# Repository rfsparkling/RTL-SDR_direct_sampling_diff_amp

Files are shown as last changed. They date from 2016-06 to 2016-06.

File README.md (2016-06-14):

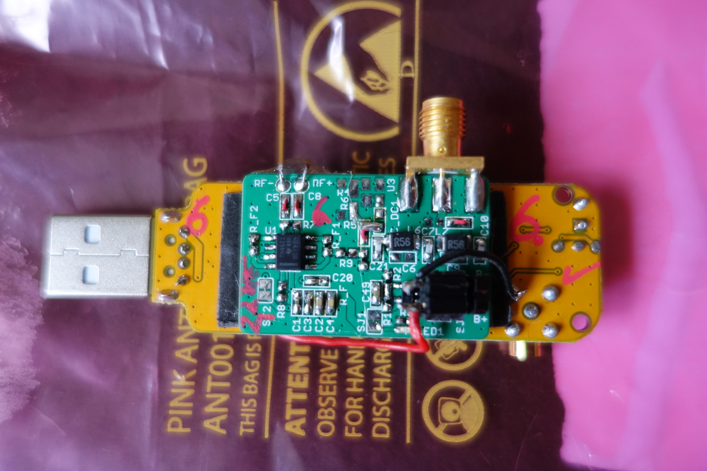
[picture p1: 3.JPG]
layout preview


This is a breakout board for stock RTL-SDR dongle, allowing the until known best direct sampling method for HF reception using a differential amplifer as BALUN. Right now filtering DC...14 MHz band but possible to work on 14...28 MHz band too after adding a Band Pass Filter BPF.

My design utilizes an LNA too, which adds about 20 dB of gain on HF band. Also a PI attenuator added right after to avoid saturation in the diff amp. The LNA main reason is to create good noise figure for the RX chain.

Thanks to Martin - G8JNJ for publishing his idea about a possible diff amp solution for direct sampling! Also for taking his time and working with me on that also testing and reviewing the first prototype.
http://www.g8jnj.net/softwaredefinedradio.htm

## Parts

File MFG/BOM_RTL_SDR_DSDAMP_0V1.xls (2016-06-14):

Qty | Value | Parts | Device | Package | Description | ALTDISTRI_NEWARK | DESCR | DISTRI | DISTRINR | MANUF | MANUFNR | MPN | OC_FARNELL | OC_NEWARK | PACKAGE | PARTNR | SUPPLIER | VENDOR
1 |  | LED1 | LED0603 | LED-0603 | LEDs
2 | 0.56uH | L6, L7 | INDUCTOR_L_1210 | L1210 |  |  | Inductor, wirewound |  |  | TDK | NLCV32 series
2 | 100 | R4, R5 | R-US_R0603 | R0603 | RESISTOR, American symbol
2 | 100nF | C1, C2 | CAP-SMD0603 | 603
2 | 10uF | C3, C4 | CAP-SMD0603 | 603
1 | 180 | R9 | R-US_R0603 | R0603 | RESISTOR, American symbol
2 | 1k | R_F1, R_F2 | R-US_R0603 | R0603 | RESISTOR, American symbol
2 | 1uF | C49, C50 | CAP-SMD0603 | 603
1 | 220 | R8 | R-US_R0603 | R0603 | RESISTOR, American symbol
7 | 220nF | C5, C8, C11, C20, C_DC0, C_DC1, C_DC2 | CAP-SMD0603 | 603
1 | 30.1k | R2 | R-US_R0603 | R0603 | RESISTOR, American symbol
2 | 330p | C10, C21 | CAP-SMD0603 | 603
1 | 470 | R3 | R-US_R0402 | R0402 | RESISTOR, American symbol
1 | 500 | R7 | R-US_R0603 | R0603 | RESISTOR, American symbol
1 | 52.3k | R1 | R-US_R0603 | R0603 | RESISTOR, American symbol
1 | 59 | R_F | R-US_R0603 | R0603 | RESISTOR, American symbol
1 | 680p | C7 | CAP-SMD0603 | 603
1 | 75 | R6 | R-US_R0603 | R0603 | RESISTOR, American symbol
1 | BGA416, LNA | U3 | BGA416 | SOT143 | RF Cascode Amplifier, Typical supply voltage: 2.5 to 5.0 V |  |  | Farnell | 2480586
2 | N.F. | C6, C9 | CAP-SMD0603 | 603
1 | PGB1010603NRHF | ESD1 | SMF33A-GS08_ESD0603 | 0603@1
1 | SMA_EDGE | SMA1 | SMA_EDGE | 142-0701-801 | RF Connectors PCB END MT JCK GLD .062 BOARD THICK" |  |  | Mouser | 530-142-0701-801 |  |  |  |  |  |  | 142-0701-801 |  | Emerson Conectivity
4 | TESTPOINT39MIL | B+, B-, RF+, RF- | TESTPOINT39MIL | TESTPOINT1,0
1 | THS4521ID | U1 | THS4521ID | SOIC127P600X175-8N | VERY LOW POWER, NEGATIVE RAIL INPUT, RAIL-TO-RAIL OUTPUT FULLY DIFFERENTIAL AMPLIFIER |  |  |  |  |  |  | THS4521ID | 1755707 | 45P2938 | SOIC-8 |  | Texas Instruments
1 | TPS73601DBVR | U2 | TPS73601DBVR | SOT95P280X145-5N | Cap-Free, NMOS, 400mA Low-Dropout Regulator with Reverse Current Protection | 87H2971 |  | Farnell | 1576489 |  |  |  |  |  | SOT-23-5 | TPS73601DBVR |  | Texas Instruments
2 | printed | SJ1, SJ2 | JUMPER_SMD_1 | JUMPER_SMD_SJ_1
1 | printed | SJ3 | JUMPER_SMD_3A | JUMPER_SMD_SJ2A

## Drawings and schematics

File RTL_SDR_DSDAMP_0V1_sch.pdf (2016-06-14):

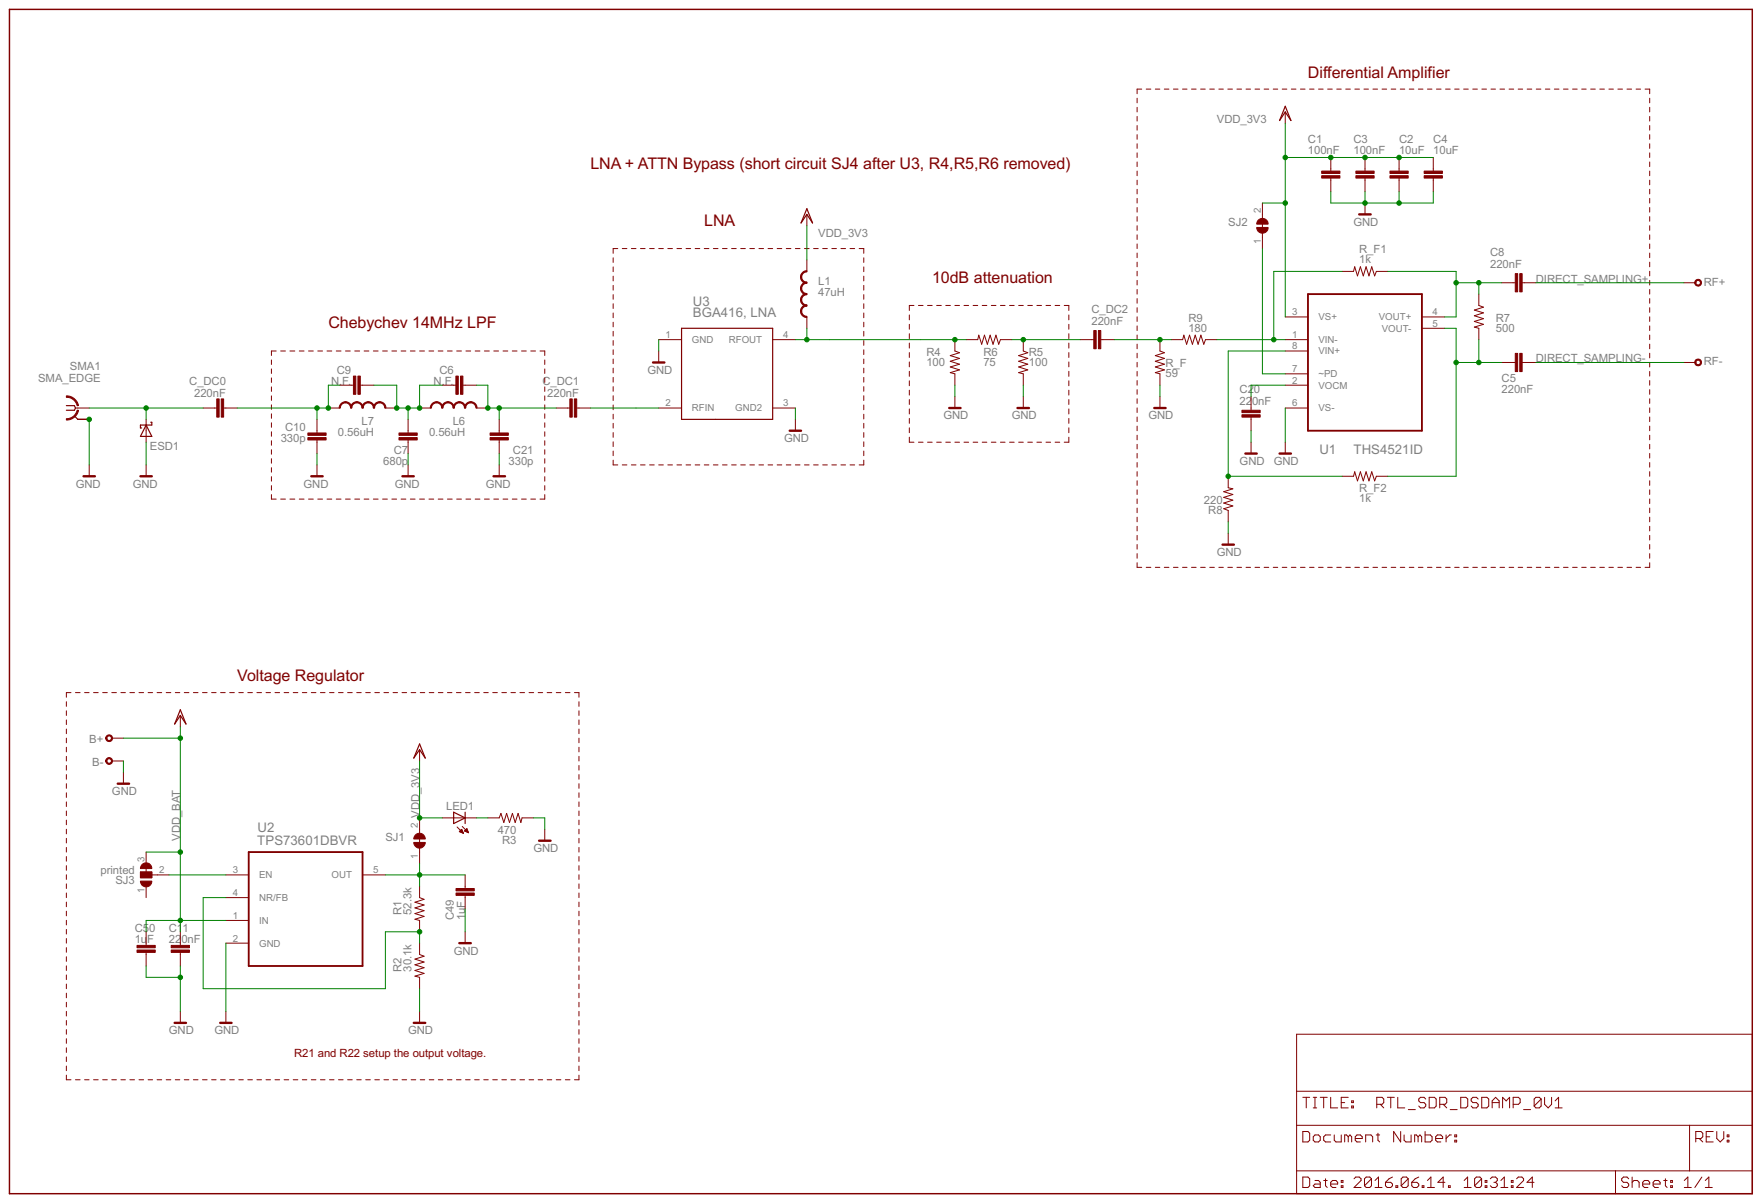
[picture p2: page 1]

LNA + ATTN Bypass (short circuit SJ4 after U3, R4,R5,R6 removed)

R21 and R22 setup the output voltage.

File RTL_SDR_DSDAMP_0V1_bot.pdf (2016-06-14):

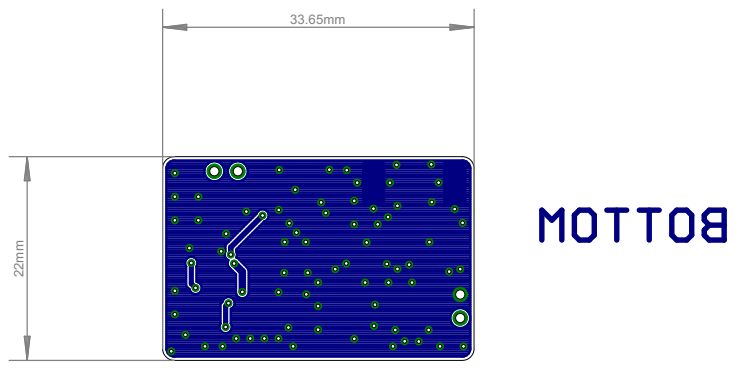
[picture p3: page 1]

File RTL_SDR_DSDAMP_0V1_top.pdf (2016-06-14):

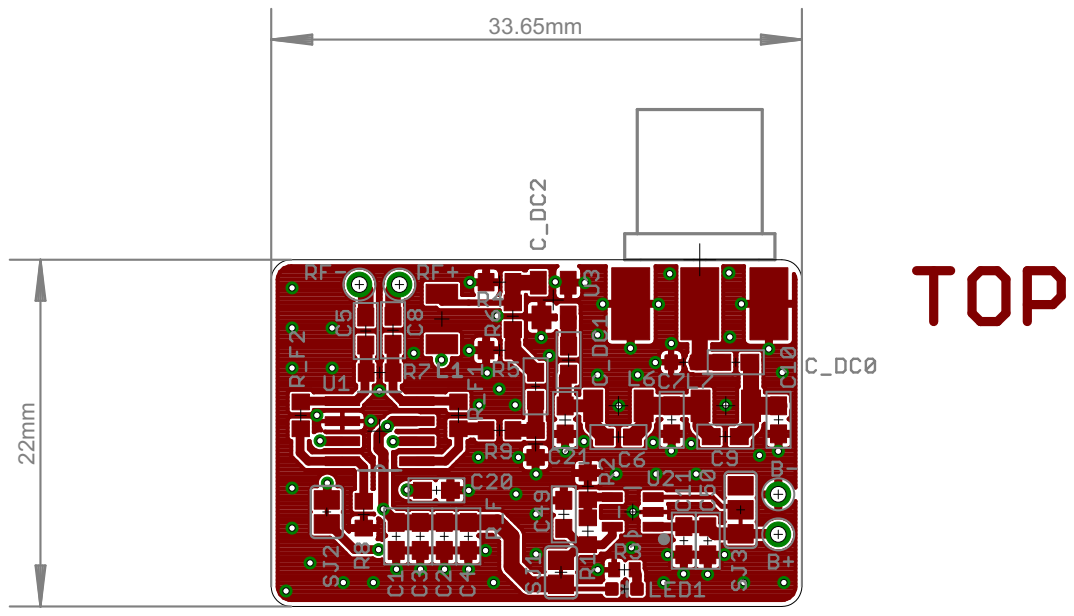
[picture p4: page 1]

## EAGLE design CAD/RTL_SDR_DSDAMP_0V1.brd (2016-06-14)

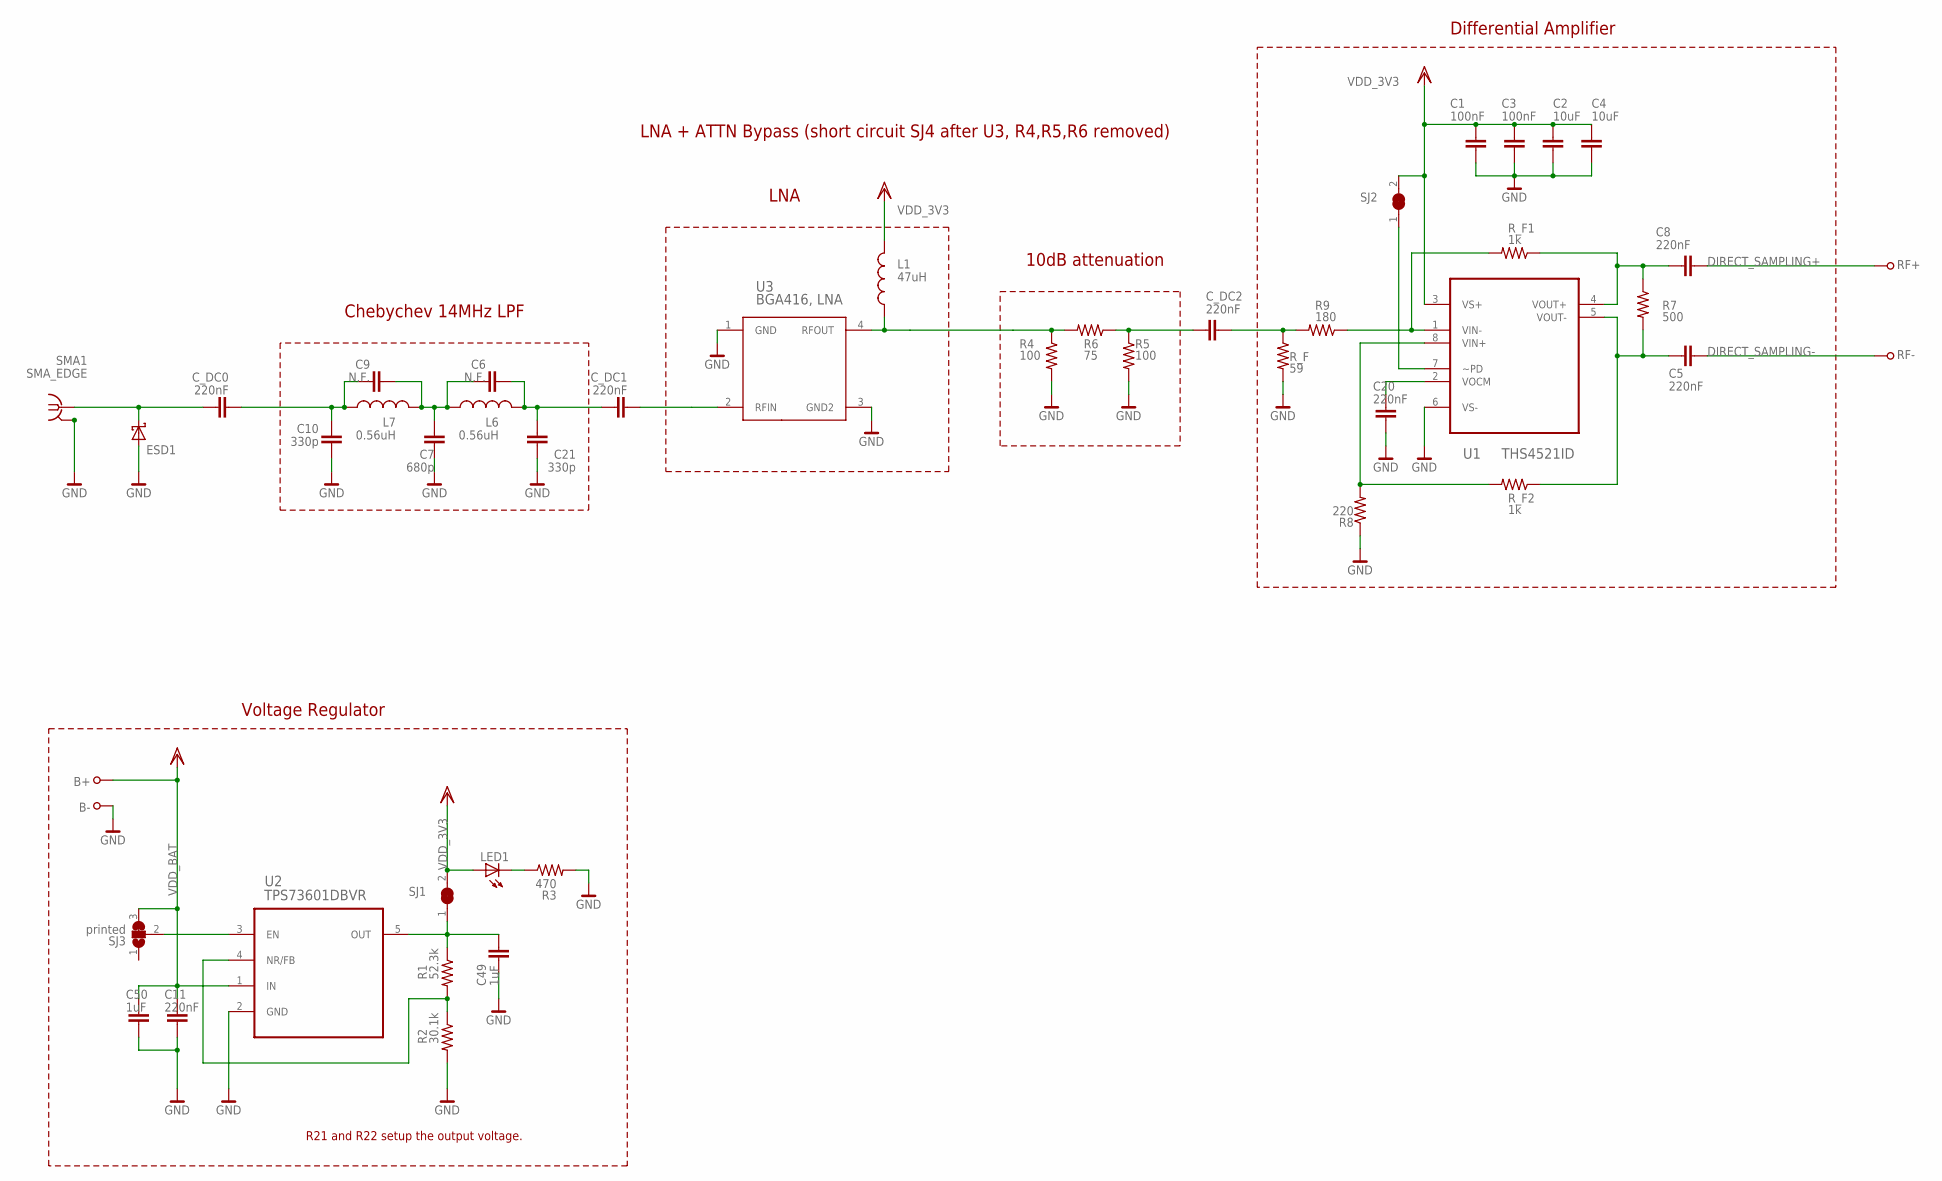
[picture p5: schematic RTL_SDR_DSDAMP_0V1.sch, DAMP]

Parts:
B+: TESTPOINT39MIL; TESTPOINT1,0
B-: TESTPOINT39MIL; TESTPOINT1,0
C1, C2: 100nF; 0603
C3, C4: 10uF; 0603
C5, C8, C11, C20: 220nF; 0603
C6, C9: N.F.; 0603
C7: 680p; 0603
C10, C21: 330p; 0603
C49, C50: 1uF; 0603
C_DC0, C_DC1, C_DC2: 220nF; 0603
ESD1: PGB1010603NRHF; 0603@1
L1: 47uH; L1210
L6, L7: 0.56uH; L1210
LED1: LED0603; LED-0603
R1: 52.3k; R0603
R2: 30.1k; R0603
R3: 470; R0402
R4, R5: 100; R0603
R6: 75; R0603
R7: 500; R0603
R8: 220; R0603
R9: 180; R0603
RF+: TESTPOINT39MIL; TESTPOINT1,0
RF-: TESTPOINT39MIL; TESTPOINT1,0
R_F: 59; R0603
R_F1, R_F2: 1k; R0603
SJ1, SJ2: printed; JUMPER_SMD_SJ_1
SJ3: printed; JUMPER_SMD_SJ2A
SMA1: SMA_EDGE; 142-0701-801
U1: THS4521ID; SOIC127P600X175-8N
U2: TPS73601DBVR; SOT95P280X145-5N
U3: BGA416, LNA; SOT143

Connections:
DIRECT_SAMPLING+: C8.1, RF+.1
DIRECT_SAMPLING-: C5.1, RF-.1
GND: B-.1, C1.1, C2.1, C3.1, C4.1, C7.1, C10.1, C11.1, C20.1, C21.1, C49.1, C50.1, ESD1.1 (A), R2.2, R3.2, R4.2, R5.2, R8.1, R_F.2, SMA1.RING@1 (2), SMA1.RING@2 (3), SMA1.RING@3 (4), SMA1.RING@4 (5), U1.6 (VS-), U2.2 (GND), U3.1 (GND), U3.3 (GND2)
unnamed: LED1.C, R3.1
unnamed: L1.2, R4.1, R6.2, U3.4 (RFOUT)
unnamed: C6.2, C21.2, C_DC1.1, L6.1
unnamed: C9.1, C10.2, C_DC0.2, L7.2
unnamed: C49.2, R1.1, SJ1.1, U2.5 (OUT)
unnamed: C5.2, R7.2, R_F2.1, U1.5 (VOUT-)
unnamed: C8.2, R7.1, R_F1.1, U1.4 (VOUT+)
unnamed: C_DC1.2, U3.2 (RFIN)
unnamed: C6.1, C7.2, C9.2, L6.2, L7.1
unnamed: C20.2, U1.2 (VOCM)
unnamed: R1.2, R2.1, U2.4 (NR/FB)
unnamed: SJ2.1, U1.7 (~PD)
unnamed: R8.2, R_F2.2, U1.8 (VIN+)
unnamed: SJ3.2, U2.3 (EN)
unnamed: C_DC2.1, R5.1, R6.1
unnamed: R9.1, R_F1.2, U1.1 (VIN-)
unnamed: C_DC0.1, ESD1.2 (C), SMA1.TIP (1)
unnamed: C_DC2.2, R9.2, R_F.1
VDD_3V3: C1.2, C2.2, C3.2, C4.2, L1.1, LED1.A, SJ1.2, SJ2.2, U1.3 (VS+)
VDD_BAT: B+.1, C11.2, C50.2, SJ3.3, U2.1 (IN)

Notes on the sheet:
R21 and R22 setup the output voltage.
10dB attenuation
Differential Amplifier
LNA
LNA + ATTN Bypass (short circuit SJ4 after U3, R4,R5,R6 removed)
Chebychev 14MHz LPF
Voltage Regulator

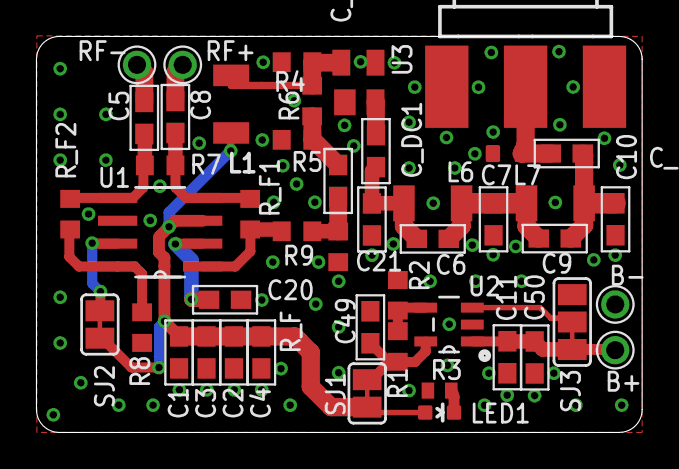
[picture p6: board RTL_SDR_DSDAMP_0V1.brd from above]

Board: 2 copper layers, 33.7 x 22.0 mm, 46 parts (0 on the bottom side), 23 nets.

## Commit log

2016-06-14 adding CAD / CAM files
    [BOM_RTL_SDR_DSDAMP_0V1.xls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]
2016-06-14 adding pictures of prototypes
2016-06-14 Adding the missing LNA VDD bias network, updating CAD / CAM / PDF files
    [DSDAMP_0V1.GTL, RTL_SDR_DSDAMP_0V1.GBL, RTL_SDR_DSDAMP_0V1.GBO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]
